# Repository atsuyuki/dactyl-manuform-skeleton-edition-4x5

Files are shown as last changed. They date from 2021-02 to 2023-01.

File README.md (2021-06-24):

# Dactyl Manuform Skeleton Edition 4x5

[Dactyl-Manuform](https://github.com/tshort/dactyl-keyboard) のリミックスモデルです。

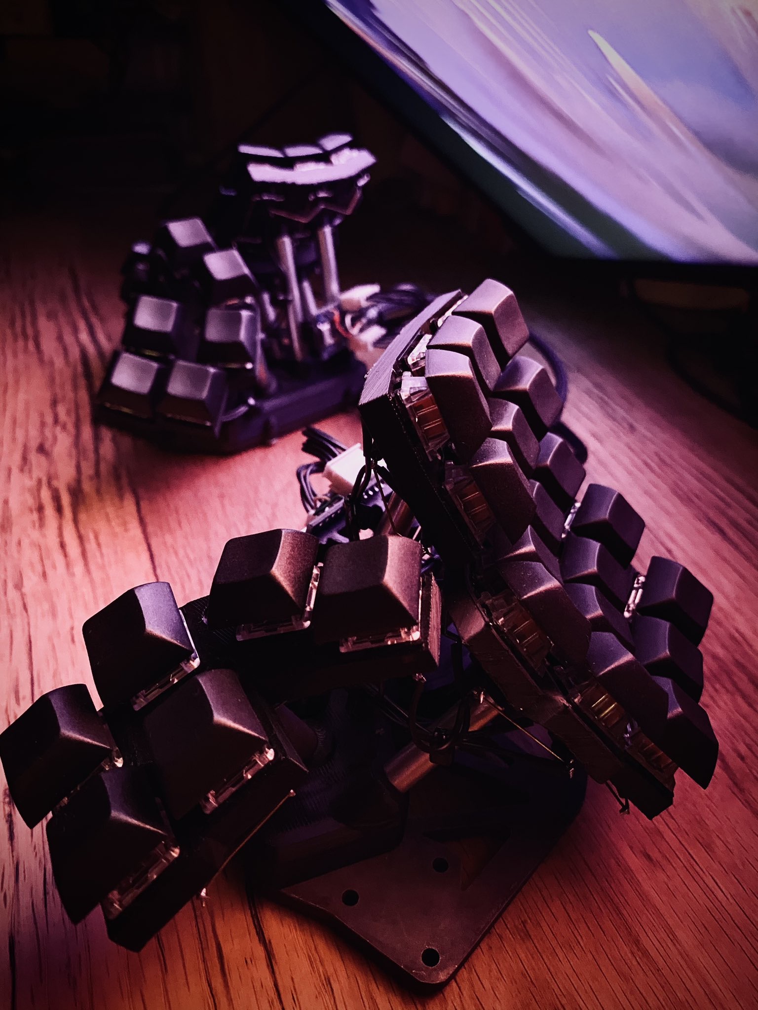
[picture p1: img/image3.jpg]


## 系統樹

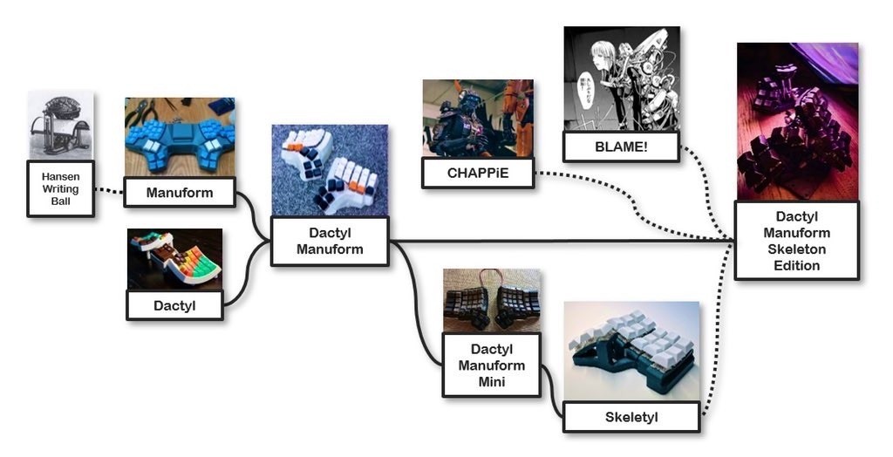
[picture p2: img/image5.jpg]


## ストーリー

[エルゴノミックな自作キーボード Dactyl Manuform のカスタムモデルを作る話—コンセプト&基本設計編—](https://www.creativity-ape.com/entry/2021/03/13/080000)

## ビルドガイド

[エルゴノミックでサイバーパンクな自作キーボード"Dactyl Manuform Skeleton Edition 4x5 "を作った話—ビルドガイド—](https://www.creativity-ape.com/entry/2021/06/18/121519)

## 3Dプリント用データ

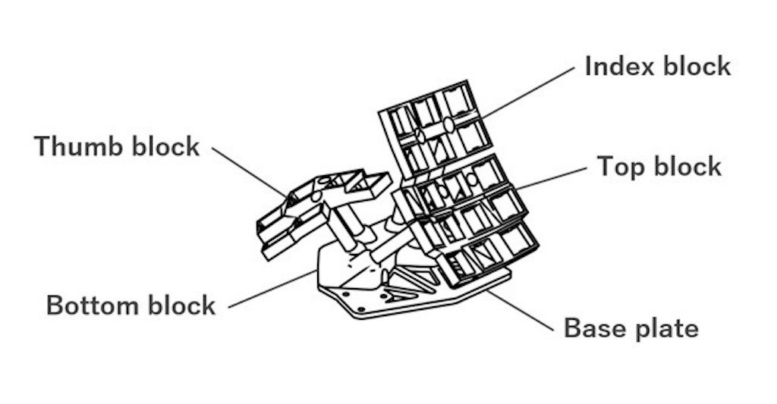
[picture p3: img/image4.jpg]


- /things
  - baseplate
  - bottom
  - top
  - index
  - thumb
  - pro micro bracket

## プロジェクトの進捗

- 最新の進捗状況は[Twitter @aaa_tu](https://twitter.com/aaa_tu/status/1351311085035429888?s=20)

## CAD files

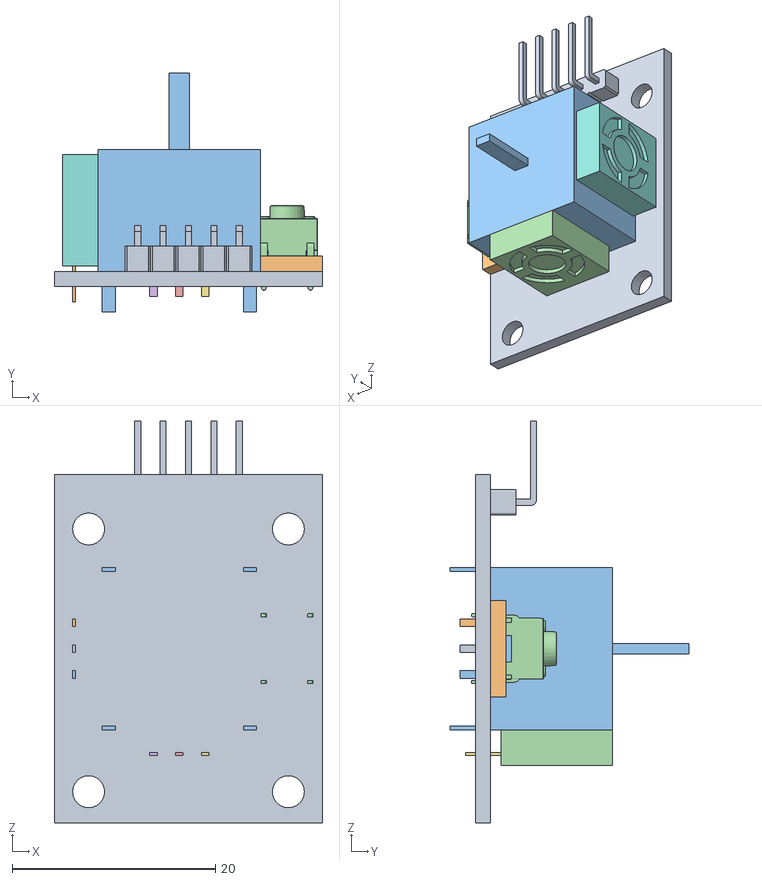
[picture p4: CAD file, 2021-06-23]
source/joystick/Joystick assembly v1.obj
26.4 x 23.5 x 39.5

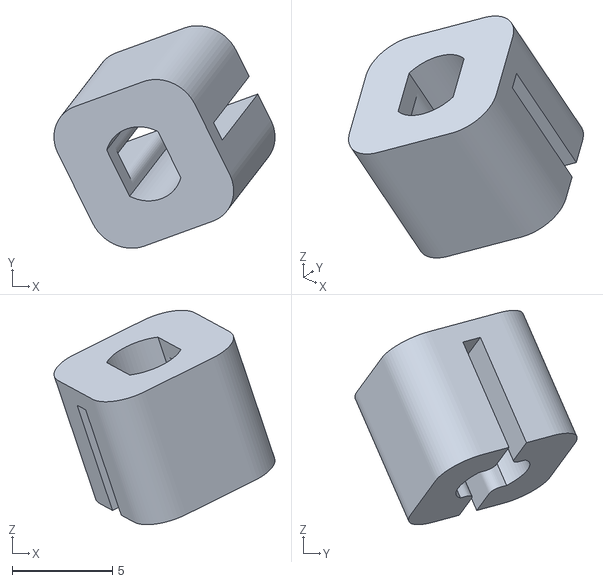
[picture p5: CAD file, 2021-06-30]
source/joystick/joystick_cap_stem.stl
11.0 x 11.1 x 10.7

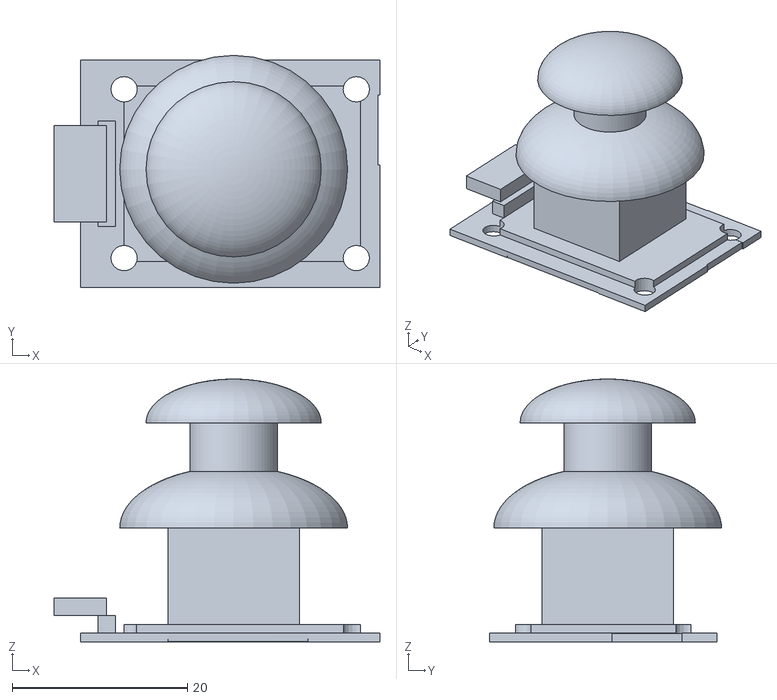
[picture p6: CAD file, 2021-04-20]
source/things/KY-023_Joystick_Module.stl
37.2 x 26.5 x 30.0

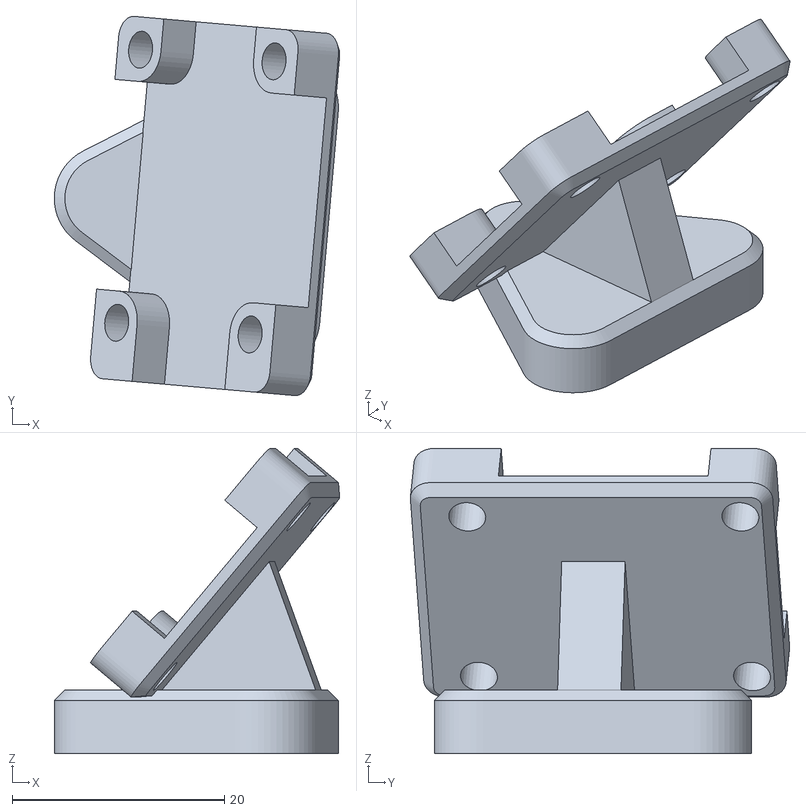
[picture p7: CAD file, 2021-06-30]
things/joystick/joystick_bracket.stl
26.9 x 35.8 x 28.8

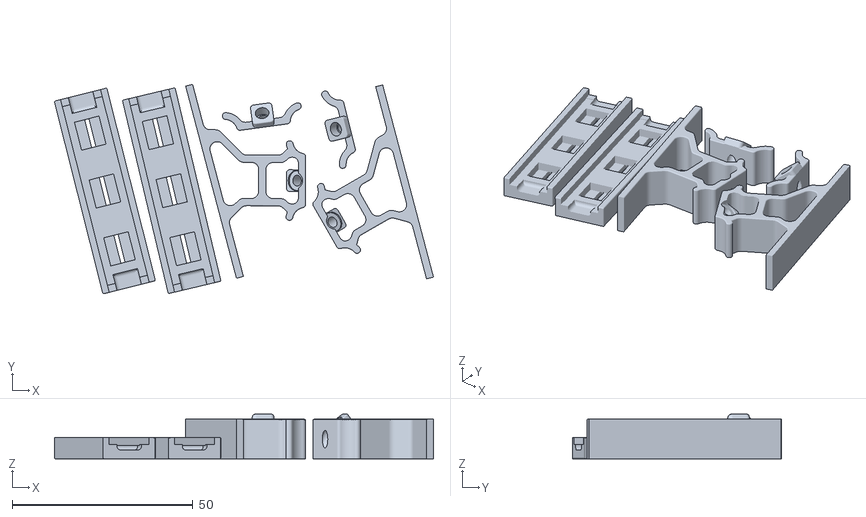
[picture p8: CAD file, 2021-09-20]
things/LED/led_bracket.stl
104.9 x 58.0 x 12.5

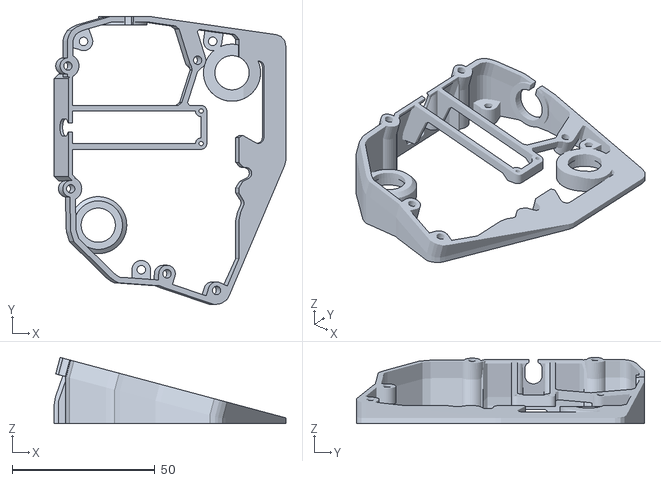
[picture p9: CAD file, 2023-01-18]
things/Raspberry-pi-pico_bracket_right.stl
81.2 x 100.8 x 23.2

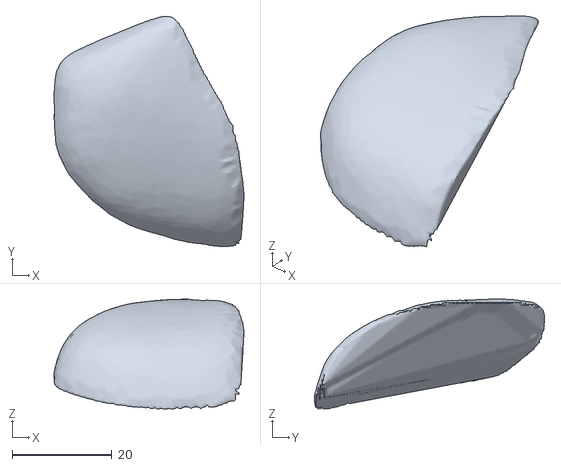
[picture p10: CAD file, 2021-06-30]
source/joystick/joystick-Clay_Model_Fixed_001.stl
38.1 x 46.2 x 22.0

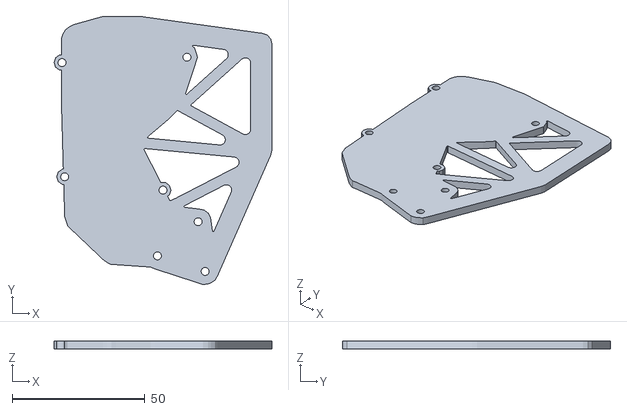
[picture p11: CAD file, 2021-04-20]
source/things/right_baseplate-design.stl
82.0 x 100.8 x 3.00

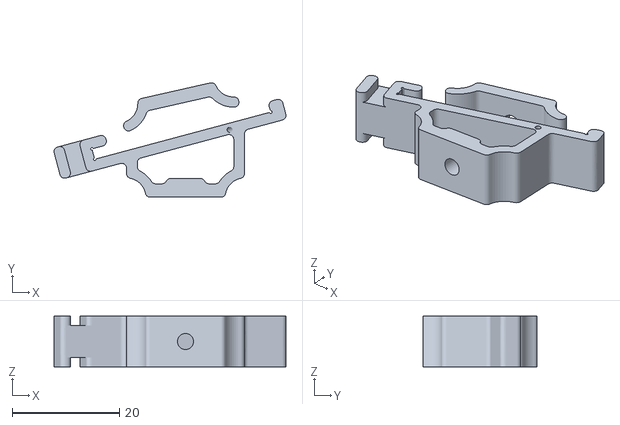
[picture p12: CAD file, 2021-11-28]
things/promicro_bracket.stl
43.3 x 21.4 x 9.50

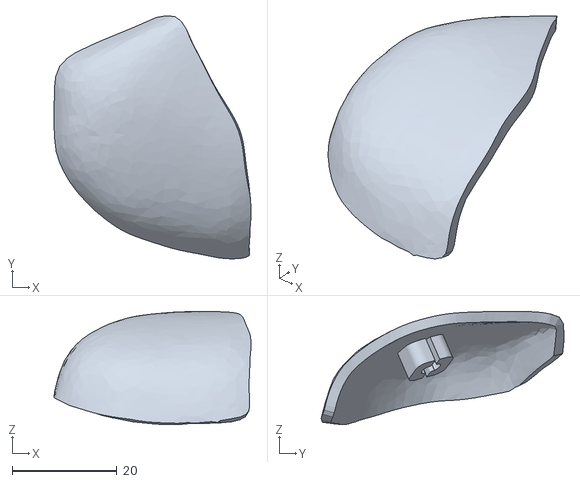
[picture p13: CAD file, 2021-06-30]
source/joystick/Joystick_Cap.stl
37.6 x 46.4 x 21.7

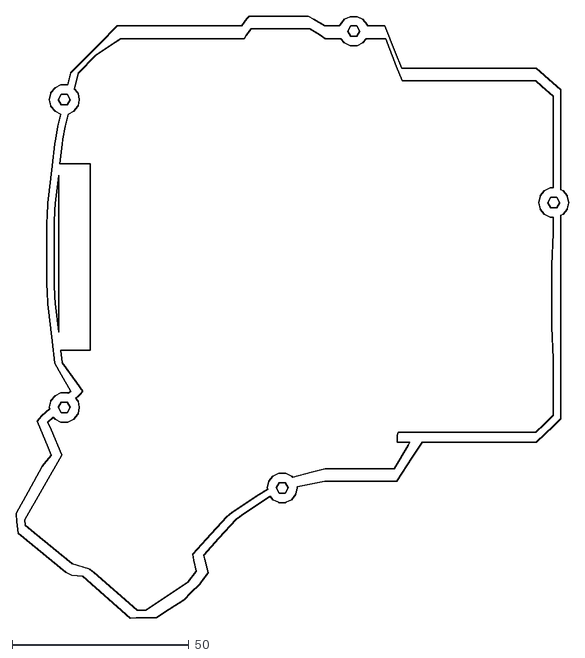
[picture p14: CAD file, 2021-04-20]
source/things/right-5x6-plate.dxf
156.5 x 170.5

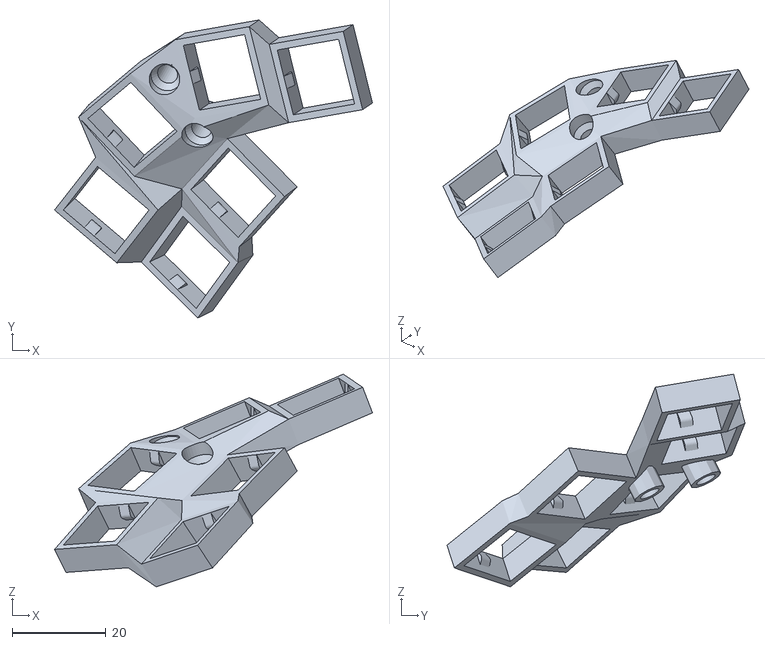
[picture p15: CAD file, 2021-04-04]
things/right_thumb.stl
67.7 x 63.5 x 45.3

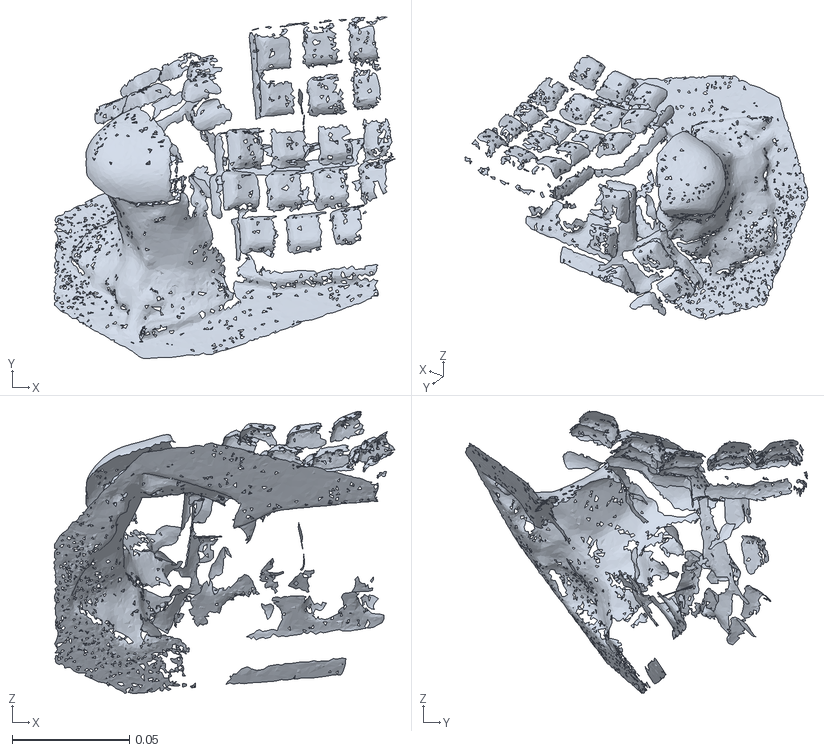
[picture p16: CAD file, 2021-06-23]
source/joystick/clay_model.stl
0.145 x 0.146 x 0.12

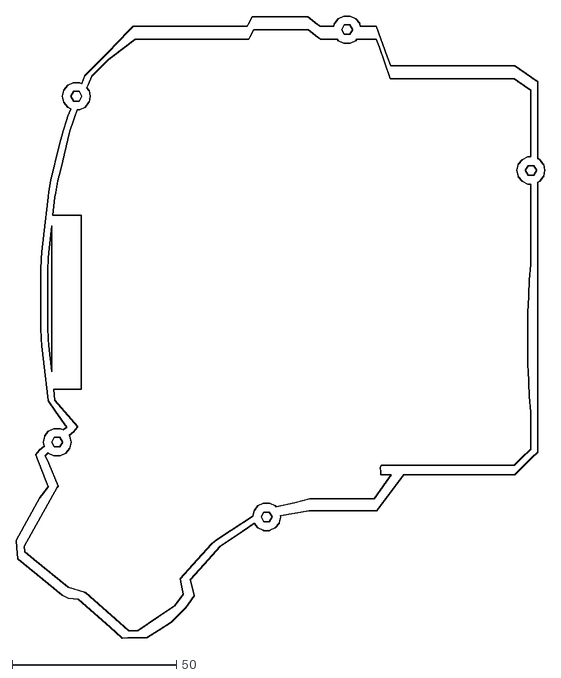
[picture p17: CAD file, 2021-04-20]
source/things/right-6x6-plate.dxf
160.9 x 189.3

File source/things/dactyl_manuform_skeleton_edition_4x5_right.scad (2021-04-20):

//use<right_fixed_module.scad>
module right() include<right.scad>
use<stand_test_3.scad>
use<misc.scad>

use<joystick_bracket.scad>
color("gray")translate([0,-102,14.9]) import("right_baseplate-design.stl");

//include<right_baseplate.scad>

joystick_block();
dm_right();
/*

difference(){
hull(){
color("yellow")translate([72, -70, 60]) rotate([50,0,30]){
  translate([0,0,-6]) cube([34,26,1],center=true);
}
translate([72, -70, 18]) rotate([0,0,30]){
translate([0,0,3])cube([34,20,6],center=true);
}
}
union(){
translate([72, -70, 18])rotate([0,0,30]){
  translate([5,0,-6])cylinder(r=1.7,h=10);
  translate([-5,0,-6])cylinder(r=1.7,h=10);
}
  }

}
    }



*/
/*
module tab(){
  hull(){
    translate([-33
    , -50, 76]){
      rotate([10, -20, 10]){
        translate([-0.5, 0.4, 0.5])cube([1, 17, 6], center = true);
      }
    }

    color("yellow", 0.8)translate([-28, -40, 73]){
        rotate([-30, 50, 0]){
          translate([-0.5, -0.5, 0])cube([1, 17, 6], center = true);
        }
      }
  }
}
*/  

module base_screws_hole(r){
  rib_height=4;
  union(){
translate([-74, -40, 18]){
  cylinder(r = r, h = rib_height); 
translate([0,0,rib_height])sphere(r);
  }
    translate([-37, -45, 18]){
      cylinder(r = r, h = rib_height); 
    translate([0,0,rib_height])sphere(r);
      }
    translate([-75, 3, 18]){
      cylinder(r = r, h = rib_height); 
    translate([0,0,rib_height])sphere(r);
      }
    translate([-28, 5, 18]){
      cylinder(r = r, h = 6); 
    translate([0,0,3])sphere(r);
      }

  }
}

//  translate([80,-55,18]) cylinder(r=3,h=6);
//  translate([55,-75,18]) cylinder(r=3,h=6);

module dm(){
// トッププレート// トッププレート
  difference(){
    union(){
      right();
      top_brackets();
      //      tab();
    }
    union(){
      rods();
      screws();
    }
  }

// ボトムプレート// ボトムプレート
  difference(){
    union(){
      base_plate();
      base_screws_hole(3);
    }
    union(){
      rods();
      screws();
      base_screws_hole(1.7);
    }
  }
}

/*
translate([-47, -11, 80])rotate([0, 16, 0]){
    translate([0, 0, -40])promicro_holder();
  }
    */  

module dm_right(){
translate([100, 0, 0]){
  dm();
  rods_nooffset();
translate([-47,-11,80]) rotate([180,180+16,0]) translate([0,0,-30]){
    import("promicro_holder.stl");
    translate([14,-29.5,-13.5])rotate([90,0,90])promicro();
    }
  //screws();
}
}



//mirror([1, 0, 0])translate([100, 0, 0])dm();

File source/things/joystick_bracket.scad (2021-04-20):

module joystick()color("#555")translate([-2.5, 0.3, 0])import("KY-023_Joystick_Module.stl");

module joystick_screw(x, y, r, h){
  translate([x, y, -3]){
    cylinder(r = r, h = h, $fs = 0.01, center = true);
  }

}

module joystick_screws(r, h){
  joystick_screw(26 / 2, -20 / 2, r, h);
  joystick_screw(26 / 2, 20 / 2, r, h);
  joystick_screw(-26 / 2, -20 / 2, r, h);
  joystick_screw(-26 / 2, 20 / 2, r, h);
}

module joystick_block(){
  difference(){
    union(){
      difference(){
        translate([75, -71, 63])rotate([15, 0, 40]){
            bracket();
            translate([0, 0, 0.1])joystick();
          }
        translate([75, -71, 31])cylinder(r = 4.1, h = 20.2, $fs = 0.01);
      }
        color("gray", 0.5)translate([75, -71, 31.1])cylinder(r = 4, h = 20, $fs = 0.01);
    }
    translate([0, -100, -100 + 18])cube([100, 100, 100]);
  }
}

joystick_block();

module bracket(){
  difference(){
    union(){
      difference(){
        union(){
          translate([0, 0, -3])cube([34, 26, 6], center = true);
          rotate([-15, 0, 0])translate([0, 0, -8])cube([12, 12, 10], center = true);
          rotate([-15, 0, 0])translate([0, 0, -45]){
              hull(){
                minkowski(){ 
                  union(){
                    cylinder(r = 4, h = 10);
                    translate([10, 10, 0])cylinder(r = 1, h = 6);
                    translate([-10, 10, 0])cylinder(r = 1, h = 6);
                    translate([0, -6, 0])cylinder(r = 1, h = 6);
                  }
                  sphere(4);
                }

              }}
          //rotate([-15, 0, 0])translate([0, 0, -12])cylinder(r=2,h=8);
        }
        union(){
          translate([-27, 0, -4 / 2])cube([27 + 2-4, 13, 10], center = true);
          translate([0, 0, -4 / 2])cube([27 + 2-4, 20 + 2+5, 4], center = true);
          translate([0, 0, -4 / 2])cube([34+2, 13, 4], center = true);
          rotate([-15, 0, 0])translate([0, 0, -12])cylinder(r = 2, h = 100, center = true, $fs = 0.01);
          rotate([-15, 0, 0])translate([0, 0, -47])cylinder(r = 4, h = 10, center = true, $fs = 0.01);
          rotate([-15, 0, 0])translate([0, 0, -5])cylinder(r = 4, h = 4, center = true);
          rotate([-15, 0, 0])translate([0, 0, -45]){
              translate([10, 10, -10])cylinder(r = 1.7, h = 16);
              translate([-10, 10, -10])cylinder(r = 1.7, h = 16);
              translate([0, -6, -10])cylinder(r = 1.7, h = 16);
            }
        }
      }
      joystick_screws(3, 6);
    }
    color("red")joystick_screws(1.7, 10);
  }
}

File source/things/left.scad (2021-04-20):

mirror ([-1, 0, 0]) {
  difference () {
    union () {
      union () {
        translate ([0, 0, 16]) {
          rotate (a=10.000000000000002, v=[0, 1, 0]) {
            translate ([0, 0, 0]) {
              translate ([0, 0, 244.80957697923077]) {
                rotate (a=20.0, v=[0, 1, 0]) {
                  translate ([0, 0, -244.80957697923077]) {
                    translate ([0, 0, 87.18393769497159]) {
                      rotate (a=14.999999999999998, v=[1, 0, 0]) {
                        translate ([0, 0, -87.18393769497159]) {
                          union () {
                            union () {
                              translate ([0, 7.95, 2]) {
                                cube ([17.4, 1.5, 4], center=true);
                              }
                              translate ([7.95, 0, 2]) {
                                cube ([1.5, 17.4, 4], center=true);
                              }
                              hull () {
                                translate ([7.95, 0, 2]) {
                                  cube ([1.5, 2.75, 4], center=true);
                                }
                                translate ([7.2, 0, 1]) {
                                  rotate (a=90.0, v=[1, 0, 0]) {
                                    cylinder ($fn=30, h=2.75, r=1, center=true);
                                  }
                                }
                              }
                            }
                            mirror ([0, 1, 0]) {
                              mirror ([1, 0, 0]) {
                                union () {
                                  translate ([0, 7.95, 2]) {
                                    cube ([17.4, 1.5, 4], center=true);
                                  }
                                  translate ([7.95, 0, 2]) {
                                    cube ([1.5, 17.4, 4], center=true);
                                  }
                                  hull () {
                                    translate ([7.95, 0, 2]) {
                                      cube ([1.5, 2.75, 4], center=true);
                                    }
                                    translate ([7.2, 0, 1]) {
                                      rotate (a=90.0, v=[1, 0, 0]) {
                                        cylinder ($fn=30, h=2.75, r=1, center=true);
                                      }
                                    }
                                  }
                                }
                              }
                            }
                          }
                        }
                      }
                    }
                  }
                }
              }
            }
          }
        }
        translate ([0, 0, 16]) {
          rotate (a=10.000000000000002, v=[0, 1, 0]) {
            translate ([0, 0, 0]) {
              translate ([0, 0, 244.80957697923077]) {
                rotate (a=20.0, v=[0, 1, 0]) {
                  translate ([0, 0, -244.80957697923077]) {
                    translate ([0, 0, 87.18393769497159]) {
                      rotate (a=0.0, v=[1, 0, 0]) {
                        translate ([0, 0, -87.18393769497159]) {
                          union () {
                            union () {
                              translate ([0, 7.95, 2]) {
                                cube ([17.4, 1.5, 4], center=true);
                              }
                              translate ([7.95, 0, 2]) {
                                cube ([1.5, 17.4, 4], center=true);
                              }
                              hull () {
                                translate ([7.95, 0, 2]) {
                                  cube ([1.5, 2.75, 4], center=true);
                                }
                                translate ([7.2, 0, 1]) {
                                  rotate (a=90.0, v=[1, 0, 0]) {
                                    cylinder ($fn=30, h=2.75, r=1, center=true);
                                  }
                                }
                              }
                            }
                            mirror ([0, 1, 0]) {
                              mirror ([1, 0, 0]) {
                                union () {
                                  translate ([0, 7.95, 2]) {
                                    cube ([17.4, 1.5, 4], center=true);
                                  }
                                  translate ([7.95, 0, 2]) {
                                    cube ([1.5, 17.4, 4], center=true);
                                  }
                                  hull () {
                                    translate ([7.95, 0, 2]) {
                                      cube ([1.5, 2.75, 4], center=true);
                                    }
                                    translate ([7.2, 0, 1]) {
                                      rotate (a=90.0, v=[1, 0, 0]) {
                                        cylinder ($fn=30, h=2.75, r=1, center=true);
                                      }
                                    }
                                  }
                                }
                              }
                            }
                          }
                        }
                      }
                    }
                  }
                }
              }
            }
          }
        }
        translate ([0, 0, 16]) {
          rotate (a=10.000000000000002, v=[0, 1, 0]) {
            translate ([0, 0, 0]) {
              translate ([0, 0, 244.80957697923077]) {
                rotate (a=20.0, v=[0, 1, 0]) {
                  translate ([0, 0, -244.80957697923077]) {
                    translate ([0, 0, 87.18393769497159]) {
                      rotate (a=-14.999999999999998, v=[1, 0, 0]) {
                        translate ([0, 0, -87.18393769497159]) {
                          union () {
                            union () {
                              translate ([0, 7.95, 2]) {
                                cube ([17.4, 1.5, 4], center=true);
                              }
                              translate ([7.95, 0, 2]) {
                                cube ([1.5, 17.4, 4], center=true);
                              }
                              hull () {
                                translate ([7.95, 0, 2]) {
                                  cube ([1.5, 2.75, 4], center=true);
                                }
                                translate ([7.2, 0, 1]) {
                                  rotate (a=90.0, v=[1, 0, 0]) {
                                    cylinder ($fn=30, h=2.75, r=1, center=true);
                                  }
                                }
                              }
                            }
                            mirror ([0, 1, 0]) {
                              mirror ([1, 0, 0]) {
                                union () {
                                  translate ([0, 7.95, 2]) {
                                    cube ([17.4, 1.5, 4], center=true);
                                  }
                                  translate ([7.95, 0, 2]) {
                                    cube ([1.5, 17.4, 4], center=true);
                                  }
                                  hull () {
                                    translate ([7.95, 0, 2]) {
                                      cube ([1.5, 2.75, 4], center=true);
                                    }
                                    translate ([7.2, 0, 1]) {
                                      rotate (a=90.0, v=[1, 0, 0]) {
                                        cylinder ($fn=30, h=2.75, r=1, center=true);
                                      }
                                    }
                                  }
                                }
                              }
                            }
                          }
                        }
                      }
                    }
                  }
                }
              }
            }
          }
        }
        translate ([0, 0, 16]) {
          rotate (a=10.000000000000002, v=[0, 1, 0]) {
            translate ([0, 0, 0]) {
              translate ([0, 0, 244.80957697923077]) {
                rotate (a=14.999999999999998, v=[0, 1, 0]) {
                  translate ([0, 0, -244.80957697923077]) {
                    translate ([0, 0, 87.18393769497159]) {
                      rotate (a=14.999999999999998, v=[1, 0, 0]) {
                        translate ([0, 0, -87.18393769497159]) {
                          union () {
                            union () {
                              translate ([0, 7.95, 2]) {
                                cube ([17.4, 1.5, 4], center=true);
                              }
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

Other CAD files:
things/right_top.stl
source/joystick/right_model.stl
source/things/right-5x6-plate-ready-to-cut.dxf
things/right_index.stl
source/things/left_mirror.scad
source/joystick/clay_model.ply
source/joystick/clay_model_fixed.stl
source/joystick/joystick v10.obj
source/joystick/joystick v8.obj
source/joystick/joystick v9.f3z
source/joystick/joystick v9.obj
source/joystick/joystick.blend
source/joystick/joystick_bracket_bottom.stl
source/joystick/joystick_bracket_top.stl
source/things/misc.scad
source/things/right-4x5-plate.dxf
source/things/right-4x6-plate.dxf
source/things/right-plate.dxf
source/things/right-plate.scad
source/things/right-test.scad
source/things/right.scad
source/things/right_baseplate-design.dxf
source/things/right_baseplate.scad
source/things/right_baseplate.stl
source/things/right_fixed_module.scad
source/things/stand.scad
source/things/stand_test_2.scad
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

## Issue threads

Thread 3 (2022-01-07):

OpenSCAD sources in the source?

dakipro, 2022-01-07:
Hey and thanks for sharing man. You mentioned that you have OpenScad files in the source, I am not able to find them, can you make sure they are uploaded?
I would like to add additional row of buttons and maybe customize something else as well
Thanks again!

atsuyuki, 2022-01-10:
Thanks for letting me know, I realized my mistake and restored the scad data from the backup.

But be careful, this source is like a labyrinth.

Closed 2022-01-10.

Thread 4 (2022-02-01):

Pinky stagger

NeighNeighNeigh, 2022-02-01:
Hello, this is a very cool design. I suffer from comical short pinkies and wonder if you may be able to offer a version with a more extreme pinky stagger, for us poor mutants?
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

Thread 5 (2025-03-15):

Adjusting tenting angle

podocarp, 2025-03-15:
Hi, I was wondering if anyone has tried a different length for the M4 rods, say perhaps 30mm and 40mm, or 20mm and 40mm, vs the default 30mm and 50mm. I'm thinking this might require changing the socket angle?

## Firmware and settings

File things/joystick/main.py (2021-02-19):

# https://wiki.seeedstudio.com/jp/Seeeduino-XIAO-CircuitPython/
# https://akizukidenshi.com/catalog/g/gM-08763/
#
# https://circuitpython.org/libraries
# - lib/adafruit_hid/mouse.mpy
# - lib/adafruit_hid/__init__.mpy
#
# Xiao     Joystick
# GND --- GND
# 3V3 --- 5V
# A10 --- VRX
# A9 --- VRY
# A8 --- SW

import time
import board
import digitalio
import usb_hid
from adafruit_hid.mouse import Mouse
from analogio import AnalogIn

mouse = Mouse(usb_hid.devices)
A9 = AnalogIn(board.A9)
A10 = AnalogIn(board.A10)

click = digitalio.DigitalInOut(board.D8)
click.direction = digitalio.Direction.INPUT
click.pull = digitalio.Pull.UP

switch_state = True

speed = 0
default_speed = 5
max_speed = 40
accel_range = max_speed - default_speed

accel_time_range = 0.8
accel_time = 0
time_step = 0.04

accel_factor = 0.0
accel_speed = 0

# フィボナッチ
# accel_curve = [0, 0.1, 0.1, 0.2, 0.3, 0.5, 0.8, 1.0]

# シグモイド
accel_curve = [
    0,
    0.01,
    0.01,
    0.01,
    0.02,
    0.02,
    0.03,
    0.04,
    0.05,
    0.06,
    0.08,
    0.1,
    0.12,
    0.15,
    0.18,
    0.22,
    0.27,
    0.32,
    0.38,
    0.44,
    0.5,
    0.56,
    0.62,
    0.68,
    0.73,
    0.78,
    0.82,
    0.85,
    0.88,
    0.9,
    0.92,
    0.94,
    0.95,
    0.96,
    0.97,
    0.98,
    0.98,
    0.99,
    0.99,
    0.99,
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
]

while True:
    x_factor = (A10.value / 65535) - 0.5
    y_factor = (A9.value / 65535) - 0.5

    power = max(abs(x_factor), abs(y_factor))

    if power > 0.1:
        accel_time += time_step
        accel_factor = accel_time / accel_time_range
        if accel_factor > 1:
            accel_factor = 1
    else:
        accel_factor = 0
        accel_time = 0

    speed = (
        default_speed
        + accel_range * accel_curve[int((len(accel_curve) - 1) * accel_factor)]
    )
    mouse.move(x=-int(x_factor * speed), y=-int(y_factor * speed))

    if not click.value and switch_state is True:
        mouse.click(Mouse.LEFT_BUTTON)
    switch_state = click.value

    print(int(switch_state), accel_time, speed / 10)

    time.sleep(time_step)

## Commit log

2021-02-19 add stl files
    [untitled-Dactyl_Manuform_Skeleton_Edition_4X5_Right_bottom.stl, untitled-Dactyl_Manuform_Skeleton_Edition_4X5_Right_index.stl, untitled-Dactyl_Manuform_Skeleto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]
2021-02-19 ファイル名変更
    [Dactyl_Manuform_Skeleton_Edition_4X5_Right_index.stl, Dactyl_Manuform_Skeleton_Edition_4X5_Right_thumb.stl, Dactyl_Manuform_Skeleton_Edition_4X5_Right_top.stl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]
2021-02-19 READMEを追加した。
2021-02-19 README更新
2021-02-19 READMEを更新
2021-02-25 ベースプレートを追加
2021-02-26 配線取り回しの設計変更
    [joystick_bracket_bottom.stl, joystick_bracket_top.stl]
2021-02-26 補強した
    [promicro_holder.stl]
2021-02-26 肉抜きした
    [right_baseplate.stl]
2021-02-26 プリントオフセットを0.1→0.2
    [right_bottom.stl, right_index.stl, right_top.stl]
2021-02-27 左手モデルを追加
    [left_baseplate.stl, left_bottom.stl, left_index.stl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]
2021-03-01 ベースプレート発注用
    [right_baseplate.dxf]
2021-03-06 尺度修正
    [right_baseplate.dxf]
2021-04-04 右手モデルを更新した
    [right_baseplate.stl, right_bottom.stl, right_index.stl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]
2021-04-20 add original dactyl manuform source
    [left-4x5.stl, left-4x6.stl, left-5x6.stl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]
2021-04-20 整理した
    [left-4x5.stl, left-4x6.stl, left-5x6.stl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]
2021-04-20 キー配列だけ取り出した
2021-04-20 add SCAD models.
    [KY-023_Joystick_Module.stl, dactyl_manuform_skeleton_edition_4x5_right.scad, joystick_bracket.scad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]
2021-05-21 Update promicro_holder.stl
    Pro Micro用ブラケットのデザインを見直した
    [promicro_holder.stl]
2021-05-24 ファイルを整理した
    [baseplate.dxf, baseplate.stl, left_baseplate.stl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]
2021-05-24 USBケーブル干渉防止のために15°の傾きをつけた
    [promicro_bracket.stl]
2021-06-20 Pro Microの固定方法を改良した
    [promicro_bracket.stl]
2021-06-23 重複ファイルなど整理
    [Joystick assembly v1.obj, KY-023_Joystick_Module.stl, clay_model.ply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]
2021-06-23 ジョイスティックのモデルを更新
    [joystick_head.stl, right_joystick_bracket.stl]
2021-06-24 README.mdを更新した
2021-06-30 ジョイスティックの設計を進めている
    [Joystick_Cap.stl, joystick-Clay_Model_Fixed_001.stl, joystick.blend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]
2021-06-30 Pro Microの固定方法を見直した
    [promicro_bracket.stl]
2021-06-30 不要ファイル整理
    [joystick_head.stl, right_joystick_bracket.stl]
2021-06-30 ジョイスティックの設計を進めた
    [joystick_bracket.stl]
2022-01-10 Recovered a lost Scad files from a backup.
    [KY-023_Joystick_Module.stl, dactyl_manuform_skeleton_edition_4x5_right.scad, joystick_bracket.scad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]
2023-01-18 Add bracket for Raspberry-pi-pico (WIP)
    To add tent angle and to use KMK firmware.
    [Raspberry-pi-pico_bracket_right.stl]
